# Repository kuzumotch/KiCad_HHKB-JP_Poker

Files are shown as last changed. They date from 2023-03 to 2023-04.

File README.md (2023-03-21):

# KiCad_HHKB-JP_Poker

## Summary
GH60互換疑似JISキーボードPCB  
GH60-compatible JIS-like hotswap keyboard PCB

<!--  ![Render](https://github.com/ai03-2725/JP60/blob/main/Render/Front.png)   -->

## Features  
- MITライセンスのもとでソース公開 / Open-source under the MIT license  
- Kailh製ソケットで全キーホットスワップ可能、はんだ付け無しで組み立て可能 / Fully hotswap  
- GH60対応の60％ケースで使用可能 / Compatible with GH60 standard cases  
- 一般的なキーサイズのみの日本語入力配列なので、GMKやePBTなどの標準キーキャップセットを使用可能 / Features a JIS-like key layout using standard keycap sizes   

[配列データ / Layout data](hhttp://www.keyboard-layout-editor.com/#/gists/5ac90f0792192c119a41c317cfdb1084)  
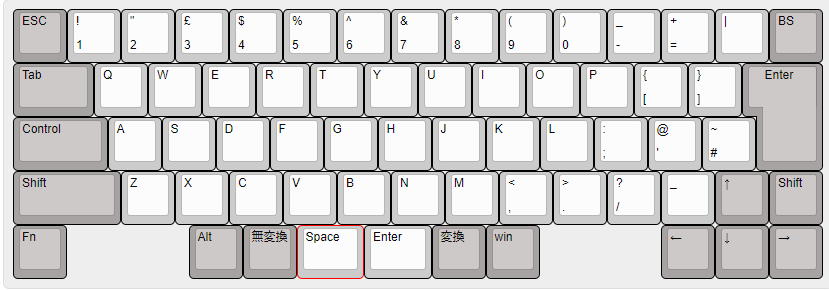
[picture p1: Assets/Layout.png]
Layout Image


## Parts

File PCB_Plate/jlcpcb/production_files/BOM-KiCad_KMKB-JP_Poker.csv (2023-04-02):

Comment | Designator | Footprint | LCSC
SMF6.0CA | D1 | D_SOD-123 | C123791
16MHz | Y1 | Crystal_SMD_3225-4Pin_3.2x2.5mm | C13738
0.1uF | C4,C5,C6 | C_0603_1608Metric | C14663
1uF | C3 | C_0603_1608Metric | C15849
22pF | C1,C2 | C_0603_1608Metric | C1653
HRO-TYPE-C-31-M-12 | USB1 | HRO-TYPE-C-31-M-12-Assembly | C165948
10uF | C7 | C_0603_1608Metric | C19702
1k | R6 | R_0603_1608Metric | C21190
5.1k | R4,R5 | R_0603_1608Metric | C23186
22 | R1,R2 | R_0603_1608Metric | C23345
10k | R3 | R_0603_1608Metric | C25804
SW_Push | SW1 | SW_SPST_TL3342 | C318884
60R@100MHz | L1 | L_1206_3216Metric | C33600
ATmega32U4-MU | U1 | QFN-44-1EP_7x7mm_P0.5mm_EP5.2x5.2mm | C45874
Polyfuse_Small | F1 | Fuse_1206_3216Metric | C70082
PRTR5V0U2X | U2 | SOT143B | C78442
SOD-123 | D10,D11,D12,D13,D14,D15,D16,D17,D18,D19,D2,D20,D21,D22,D23,D24,D25,D26,D27,D28,D29,D3,D30,D31,D32,D33,D34,D35,D36,D37,D38,D39,D4,D40,D41,D42,D43,D44,D45,D46,D47,D48,D49,D5,D50,D51,D52,D53,D54,D55,D56,D57,D58,D59,D6,D60,D61,D62,D63,D64,D65,D66,D67,D7,D8,D9 | D_SOD-123 | C81598

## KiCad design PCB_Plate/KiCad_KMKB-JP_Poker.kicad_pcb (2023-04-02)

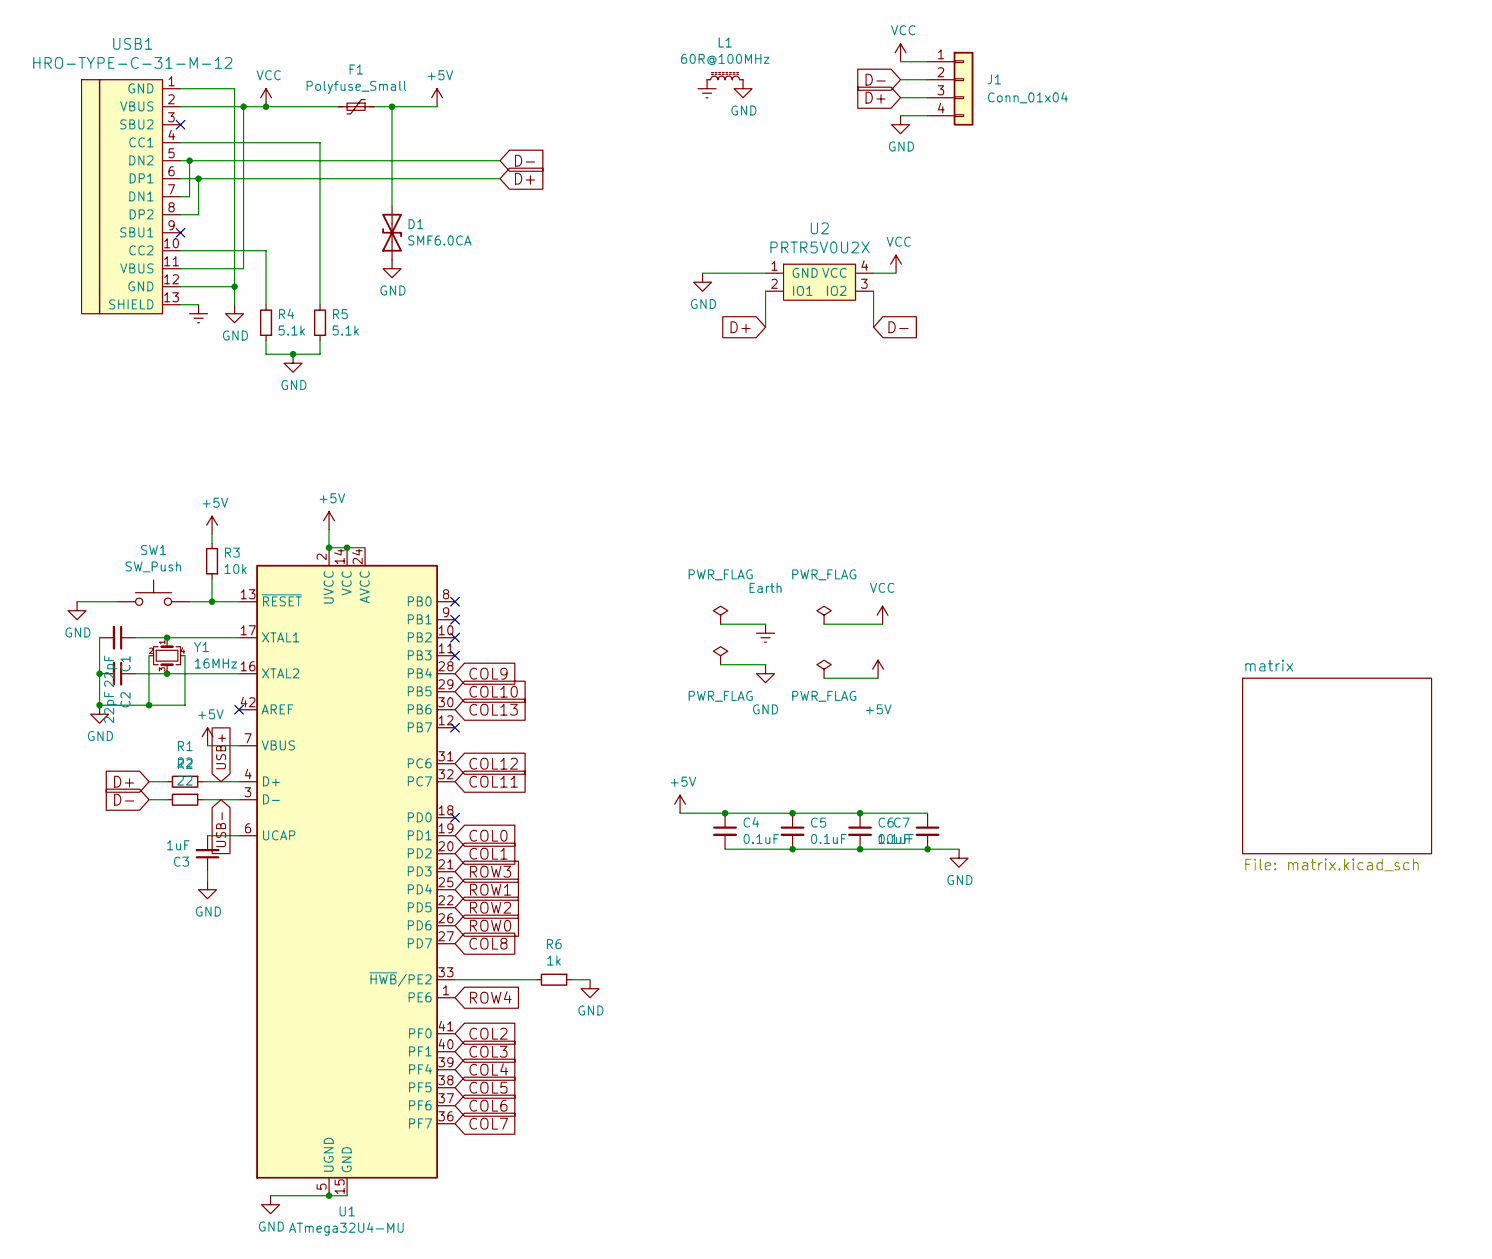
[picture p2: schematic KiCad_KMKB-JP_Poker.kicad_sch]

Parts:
C1, C2: 22pF; C_0603_1608Metric
C3: 1uF; C_0603_1608Metric
C4, C5, C6: 0.1uF; C_0603_1608Metric
C7: 10uF; C_0603_1608Metric
D1: SMF6.0CA; D_SOD-123
F1: Polyfuse_Small; Fuse_1206_3216Metric
J1: Conn_01x04; PinHeader_1x04_P2.54mm_Vertical
L1: 60R@100MHz; L_1206_3216Metric
R1, R2: 22; R_0603_1608Metric
R3: 10k; R_0603_1608Metric
R4, R5: 5.1k; R_0603_1608Metric
R6: 1k; R_0603_1608Metric
SW1: SW_Push; SW_SPST_TL3342
U1: ATmega32U4-MU; QFN-44-1EP_7x7mm_P0.5mm_EP5.2x5.2mm
U2: PRTR5V0U2X; SOT143B
USB1: HRO-TYPE-C-31-M-12; HRO-TYPE-C-31-M-12-Assembly
Y1: 16MHz; Crystal_SMD_3225-4Pin_3.2x2.5mm

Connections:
+5V: C4.1, C5.1, C6.1, C7.1, D1.2 (A2), F1.1, R3.2, U1.2 (UVCC), U1.7 (VBUS), U1.14 (VCC), U1.24 (AVCC), U1.34 (VCC), U1.44 (AVCC)
COL0: U1.19 (PD1); also elsewhere on the board
COL1: U1.20 (PD2); also elsewhere on the board
COL2: U1.41 (PF0); also elsewhere on the board
COL3: U1.40 (PF1); also elsewhere on the board
COL4: U1.39 (PF4); also elsewhere on the board
COL5: U1.38 (PF5); also elsewhere on the board
COL6: U1.37 (PF6); also elsewhere on the board
COL7: U1.36 (PF7); also elsewhere on the board
COL8: U1.27 (PD7); also elsewhere on the board
COL9: U1.28 (PB4); also elsewhere on the board
COL10: U1.29 (PB5); also elsewhere on the board
COL11: U1.32 (PC7); also elsewhere on the board
COL12: U1.31 (PC6); also elsewhere on the board
COL13: U1.30 (PB6); also elsewhere on the board
D+: J1.3, R1.2, U2.2 (IO1), USB1.6 (DP1), USB1.8 (DP2)
D-: J1.2, R2.2, U2.3 (IO2), USB1.5 (DN2), USB1.7 (DN1)
Earth: L1.1, USB1.13 (SHIELD)
GND: C1.2, C2.2, C3.1, C4.2, C5.2, C6.2, C7.2, D1.1 (A1), J1.4, L1.2, R4.1, R5.1, R6.1, SW1.1, U1.5 (UGND), U1.15 (GND), U1.23 (GND), U1.35 (GND), U1.43 (GND), U1.45 (GND), U2.1 (GND), USB1.1 (GND), USB1.12 (GND), Y1.2, Y1.4
unnamed: C1.1, U1.17 (XTAL1), Y1.1
unnamed: C2.1, U1.16 (XTAL2), Y1.3
unnamed: C3.2, U1.6 (UCAP)
unnamed: R3.1, SW1.2, U1.13 (~RESET)
unnamed: R4.2, USB1.10 (CC2)
unnamed: R5.2, USB1.4 (CC1)
unnamed: R6.2, U1.33 (~HWB/PE2)
ROW0: U1.26 (PD6); also elsewhere on the board
ROW1: U1.25 (PD4); also elsewhere on the board
ROW2: U1.22 (PD5); also elsewhere on the board
ROW3: U1.21 (PD3); also elsewhere on the board
ROW4: U1.1 (PE6); also elsewhere on the board
USB+: R1.1, U1.4 (D+)
USB-: R2.1, U1.3 (D-)
VCC: F1.2, J1.1, U2.4 (VCC), USB1.2 (VBUS), USB1.11 (VBUS)

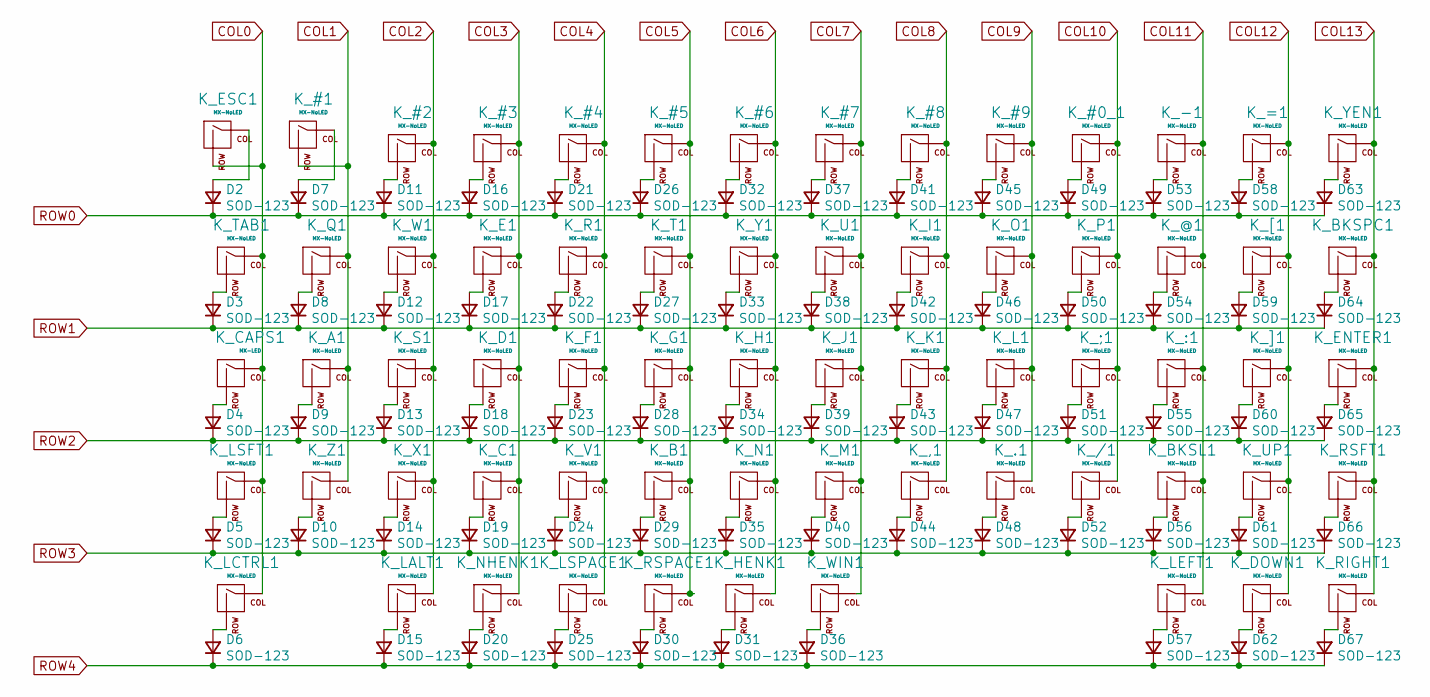
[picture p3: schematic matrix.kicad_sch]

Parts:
D2, D3, D4, D5, D6, D7, D8, D9, D10, D11, D12, D13, D14, D15, D16, D17, D18, D19, D20, D21, D22, D23, D24, D25, D26, D27, D28, D29, D30, D31, D32, D33, D34, D35, D36, D37, D38, D39, D40, D41, D42, D43, D44, D45, D46, D47, D48, D49, D50, D51, D52, D53, D54, D55, D56, D57, D58, D59, D60, D61, D62, D63, D64, D65, D66, D67: SOD-123; D_SOD-123
K_#0_1, K_#1, K_#2, K_#3, K_#4, K_#5, K_#6, K_#7, K_#8, K_#9: MX-NoLED; MXOnly-1U-Hotswap
K_,1: MX-NoLED; MXOnly-1U-Hotswap
K_-1: MX-NoLED; MXOnly-1U-Hotswap
K_.1: MX-NoLED; MXOnly-1U-Hotswap
K_/1: MX-NoLED; MXOnly-1U-Hotswap
K_:1: MX-NoLED; MXOnly-1U-Hotswap
K_;1: MX-NoLED; MXOnly-1U-Hotswap
K_=1: MX-NoLED; MXOnly-1U-Hotswap
K_@1: MX-NoLED; MXOnly-1U-Hotswap
K_A1: MX-NoLED; MXOnly-1U-Hotswap
K_B1: MX-NoLED; MXOnly-1U-Hotswap
K_BKSL1: MX-NoLED; MXOnly-1U-Hotswap
K_BKSPC1: MX-NoLED; MXOnly-1U-Hotswap
K_C1: MX-NoLED; MXOnly-1U-Hotswap
K_CAPS1: MX-LED; MXOnly-1.75U-Hotswap
K_D1: MX-NoLED; MXOnly-1U-Hotswap
K_DOWN1: MX-NoLED; MXOnly-1U-Hotswap
K_E1: MX-NoLED; MXOnly-1U-Hotswap
K_ENTER1: MX-NoLED; MXOnly-ISO-ROTATED-Hotswap
K_ESC1: MX-NoLED; MXOnly-1U-Hotswap
K_F1: MX-NoLED; MXOnly-1U-Hotswap
K_G1: MX-NoLED; MXOnly-1U-Hotswap
K_H1: MX-NoLED; MXOnly-1U-Hotswap
K_HENK1: MX-NoLED; MXOnly-1U-Hotswap
K_I1: MX-NoLED; MXOnly-1U-Hotswap
K_J1: MX-NoLED; MXOnly-1U-Hotswap
K_K1: MX-NoLED; MXOnly-1U-Hotswap
K_L1: MX-NoLED; MXOnly-1U-Hotswap
K_LALT1: MX-NoLED; MXOnly-1U-Hotswap
K_LCTRL1: MX-NoLED; MXOnly-1U-Hotswap
K_LEFT1: MX-NoLED; MXOnly-1U-Hotswap
K_LSFT1: MX-NoLED; MXOnly-2U-Hotswap
K_LSPACE1: MX-NoLED; MXOnly-1.25U-Hotswap
K_M1: MX-NoLED; MXOnly-1U-Hotswap
K_N1: MX-NoLED; MXOnly-1U-Hotswap
K_NHENK1: MX-NoLED; MXOnly-1U-Hotswap
K_O1: MX-NoLED; MXOnly-1U-Hotswap
K_P1: MX-NoLED; MXOnly-1U-Hotswap
K_Q1: MX-NoLED; MXOnly-1U-Hotswap
K_R1: MX-NoLED; MXOnly-1U-Hotswap
K_RIGHT1: MX-NoLED; MXOnly-1U-Hotswap
K_RSFT1: MX-NoLED; MXOnly-1U-Hotswap
K_RSPACE1: MX-NoLED; MXOnly-1.25U-Hotswap
K_S1: MX-NoLED; MXOnly-1U-Hotswap
K_T1: MX-NoLED; MXOnly-1U-Hotswap
K_TAB1: MX-NoLED; MXOnly-1.5U-Hotswap
K_U1: MX-NoLED; MXOnly-1U-Hotswap
K_UP1: MX-NoLED; MXOnly-1U-Hotswap
K_V1: MX-NoLED; MXOnly-1U-Hotswap
K_W1: MX-NoLED; MXOnly-1U-Hotswap
K_WIN1: MX-NoLED; MXOnly-1U-Hotswap
K_X1: MX-NoLED; MXOnly-1U-Hotswap
K_Y1: MX-NoLED; MXOnly-1U-Hotswap
K_YEN1: MX-NoLED; MXOnly-1U-Hotswap
K_Z1: MX-NoLED; MXOnly-1U-Hotswap
K_[1: MX-NoLED; MXOnly-1U-Hotswap
K_]1: MX-NoLED; MXOnly-1U-Hotswap

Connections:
COL0: K_CAPS1.1 (COL), K_ESC1.2 (ROW), K_LCTRL1.1 (COL), K_LSFT1.1 (COL), K_TAB1.1 (COL); also elsewhere on the board
COL1: K_#1.2 (ROW), K_A1.1 (COL), K_Q1.1 (COL), K_Z1.1 (COL); also elsewhere on the board
COL2: K_#2.1 (COL), K_LALT1.1 (COL), K_S1.1 (COL), K_W1.1 (COL), K_X1.1 (COL); also elsewhere on the board
COL3: K_#3.1 (COL), K_C1.1 (COL), K_D1.1 (COL), K_E1.1 (COL), K_NHENK1.1 (COL); also elsewhere on the board
COL4: K_#4.1 (COL), K_F1.1 (COL), K_LSPACE1.1 (COL), K_R1.1 (COL), K_V1.1 (COL); also elsewhere on the board
COL5: K_#5.1 (COL), K_B1.1 (COL), K_G1.1 (COL), K_RSPACE1.1 (COL), K_T1.1 (COL); also elsewhere on the board
COL6: K_#6.1 (COL), K_H1.1 (COL), K_HENK1.1 (COL), K_N1.1 (COL), K_Y1.1 (COL); also elsewhere on the board
COL7: K_#7.1 (COL), K_J1.1 (COL), K_M1.1 (COL), K_U1.1 (COL), K_WIN1.1 (COL); also elsewhere on the board
COL8: K_#8.1 (COL), K_,1.1 (COL), K_I1.1 (COL), K_K1.1 (COL); also elsewhere on the board
COL9: K_#9.1 (COL), K_.1.1 (COL), K_L1.1 (COL), K_O1.1 (COL); also elsewhere on the board
COL10: K_#0_1.1 (COL), K_/1.1 (COL), K_;1.1 (COL), K_P1.1 (COL); also elsewhere on the board
COL11: K_-1.1 (COL), K_:1.1 (COL), K_@1.1 (COL), K_BKSL1.1 (COL), K_LEFT1.1 (COL); also elsewhere on the board
COL12: K_=1.1 (COL), K_DOWN1.1 (COL), K_UP1.1 (COL), K_[1.1 (COL), K_]1.1 (COL); also elsewhere on the board
COL13: K_BKSPC1.1 (COL), K_ENTER1.1 (COL), K_RIGHT1.1 (COL), K_RSFT1.1 (COL), K_YEN1.1 (COL); also elsewhere on the board
unnamed: D2.2 (A), K_ESC1.1 (COL)
unnamed: D3.2 (A), K_TAB1.2 (ROW)
unnamed: D4.2 (A), K_CAPS1.2 (ROW)
unnamed: D5.2 (A), K_LSFT1.2 (ROW)
unnamed: D6.2 (A), K_LCTRL1.2 (ROW)
unnamed: D7.2 (A), K_#1.1 (COL)
unnamed: D8.2 (A), K_Q1.2 (ROW)
unnamed: D9.2 (A), K_A1.2 (ROW)
unnamed: D10.2 (A), K_Z1.2 (ROW)
unnamed: D11.2 (A), K_#2.2 (ROW)
unnamed: D12.2 (A), K_W1.2 (ROW)
unnamed: D13.2 (A), K_S1.2 (ROW)
unnamed: D14.2 (A), K_X1.2 (ROW)
unnamed: D15.2 (A), K_LALT1.2 (ROW)
unnamed: D16.2 (A), K_#3.2 (ROW)
unnamed: D17.2 (A), K_E1.2 (ROW)
unnamed: D18.2 (A), K_D1.2 (ROW)
unnamed: D19.2 (A), K_C1.2 (ROW)
unnamed: D20.2 (A), K_NHENK1.2 (ROW)
unnamed: D21.2 (A), K_#4.2 (ROW)
unnamed: D22.2 (A), K_R1.2 (ROW)
unnamed: D23.2 (A), K_F1.2 (ROW)
unnamed: D24.2 (A), K_V1.2 (ROW)
unnamed: D25.2 (A), K_LSPACE1.2 (ROW)
unnamed: D26.2 (A), K_#5.2 (ROW)
unnamed: D27.2 (A), K_T1.2 (ROW)
unnamed: D28.2 (A), K_G1.2 (ROW)
unnamed: D29.2 (A), K_B1.2 (ROW)
unnamed: D30.2 (A), K_RSPACE1.2 (ROW)
unnamed: D31.2 (A), K_HENK1.2 (ROW)
unnamed: D32.2 (A), K_#6.2 (ROW)
unnamed: D33.2 (A), K_Y1.2 (ROW)
unnamed: D34.2 (A), K_H1.2 (ROW)
unnamed: D35.2 (A), K_N1.2 (ROW)
unnamed: D36.2 (A), K_WIN1.2 (ROW)
unnamed: D37.2 (A), K_#7.2 (ROW)
unnamed: D38.2 (A), K_U1.2 (ROW)
unnamed: D39.2 (A), K_J1.2 (ROW)
unnamed: D40.2 (A), K_M1.2 (ROW)
unnamed: D41.2 (A), K_#8.2 (ROW)
unnamed: D42.2 (A), K_I1.2 (ROW)
unnamed: D43.2 (A), K_K1.2 (ROW)
unnamed: D44.2 (A), K_,1.2 (ROW)
unnamed: D45.2 (A), K_#9.2 (ROW)
unnamed: D46.2 (A), K_O1.2 (ROW)
unnamed: D47.2 (A), K_L1.2 (ROW)
unnamed: D48.2 (A), K_.1.2 (ROW)
unnamed: D49.2 (A), K_#0_1.2 (ROW)
unnamed: D50.2 (A), K_P1.2 (ROW)
unnamed: D51.2 (A), K_;1.2 (ROW)
unnamed: D52.2 (A), K_/1.2 (ROW)
unnamed: D53.2 (A), K_-1.2 (ROW)
unnamed: D54.2 (A), K_@1.2 (ROW)
unnamed: D55.2 (A), K_:1.2 (ROW)
unnamed: D56.2 (A), K_BKSL1.2 (ROW)
unnamed: D57.2 (A), K_LEFT1.2 (ROW)
unnamed: D58.2 (A), K_=1.2 (ROW)
unnamed: D59.2 (A), K_[1.2 (ROW)
unnamed: D60.2 (A), K_]1.2 (ROW)
unnamed: D61.2 (A), K_UP1.2 (ROW)
unnamed: D62.2 (A), K_DOWN1.2 (ROW)
unnamed: D63.2 (A), K_YEN1.2 (ROW)
unnamed: D64.2 (A), K_BKSPC1.2 (ROW)
unnamed: D65.2 (A), K_ENTER1.2 (ROW)
unnamed: D66.2 (A), K_RSFT1.2 (ROW)
unnamed: D67.2 (A), K_RIGHT1.2 (ROW)
ROW0: D2.1 (K), D7.1 (K), D11.1 (K), D16.1 (K), D21.1 (K), D26.1 (K), D32.1 (K), D37.1 (K), D41.1 (K), D45.1 (K), D49.1 (K), D53.1 (K), D58.1 (K), D63.1 (K); also elsewhere on the board
ROW1: D3.1 (K), D8.1 (K), D12.1 (K), D17.1 (K), D22.1 (K), D27.1 (K), D33.1 (K), D38.1 (K), D42.1 (K), D46.1 (K), D50.1 (K), D54.1 (K), D59.1 (K), D64.1 (K); also elsewhere on the board
ROW2: D4.1 (K), D9.1 (K), D13.1 (K), D18.1 (K), D23.1 (K), D28.1 (K), D34.1 (K), D39.1 (K), D43.1 (K), D47.1 (K), D51.1 (K), D55.1 (K), D60.1 (K), D65.1 (K); also elsewhere on the board
ROW3: D5.1 (K), D10.1 (K), D14.1 (K), D19.1 (K), D24.1 (K), D29.1 (K), D35.1 (K), D40.1 (K), D44.1 (K), D48.1 (K), D52.1 (K), D56.1 (K), D61.1 (K), D66.1 (K); also elsewhere on the board
ROW4: D6.1 (K), D15.1 (K), D20.1 (K), D25.1 (K), D30.1 (K), D31.1 (K), D36.1 (K), D57.1 (K), D62.1 (K), D67.1 (K); also elsewhere on the board

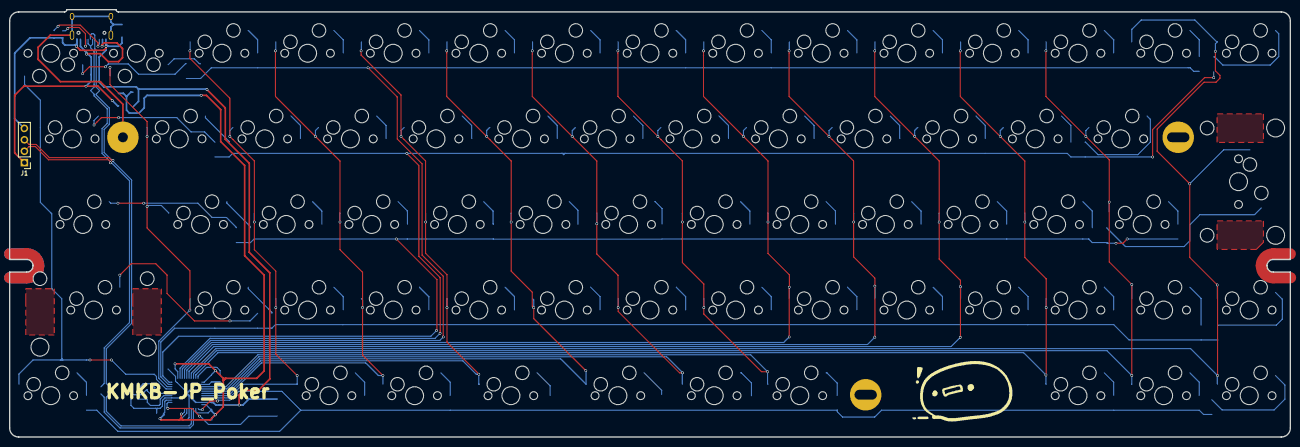
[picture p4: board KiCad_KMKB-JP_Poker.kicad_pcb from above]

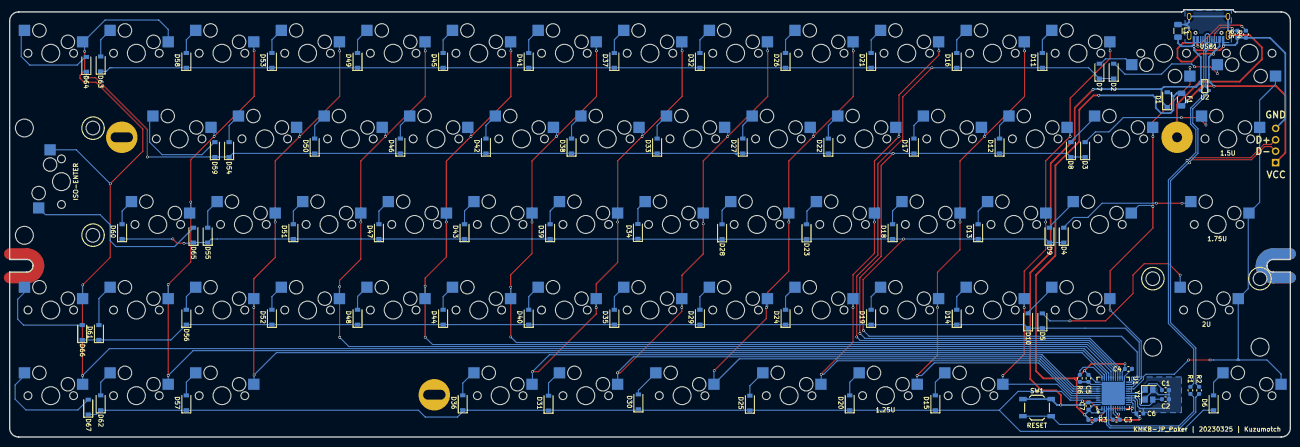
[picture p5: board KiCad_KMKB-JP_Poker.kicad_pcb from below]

Board: 2 copper layers, 285.0 x 95.1 mm, 154 parts (87 on the bottom side), 100 nets.

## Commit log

2023-03-21 initialize for KiCad_HHKB-JP_Poker
    [JP60-B_Cu.gbl, JP60-B_Mask.gbs, JP60-B_Paste.gbp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]
2023-03-21 edit symbol it does not exist in 6.0
    [KiCad_HHKB-JP_Poker.kicad_sch, matrix.kicad_sch]
2023-03-21 Edit Key Matrix
    [KiCad_HHKB-JP_Poker.kicad_sch, matrix.kicad_sch]
2023-03-21 edit footprint of Keyswitches.
    [KiCad_HHKB-JP_Poker.kicad_sch, matrix.kicad_sch]
2023-03-21 Edit sch, execute ERC, and fix warnings
    [KiCad_HHKB-JP_Poker.kicad_sch]
2023-03-21 Modify Symbol Name
    [KiCad_HHKB-JP_Poker.kicad_sch, matrix.kicad_sch]
2023-03-21 回路図に反映
2023-03-21 Create New Locallib (DZ60 Outline, but does not have center hole)
2023-03-21 Save Point 1 (Start PCB Editing)
2023-03-21 Save Point 2 (Remove ai03's logos)
    [KiCad_HHKB-JP_Poker.kicad_pcb]
2023-03-21 Save Point 3 (Remove F:Cu on R4)
    [KiCad_HHKB-JP_Poker.kicad_pcb]
2023-03-21 Save Point4 (Move MCU)
    [KiCad_HHKB-JP_Poker.kicad_pcb]
2023-03-21 Save Point 5 (Remove B:Cu on R4)
    [KiCad_HHKB-JP_Poker.kicad_pcb]
2023-03-21 Correct Symbol Names (bkspとかの辺)
    [KiCad_HHKB-JP_Poker.kicad_pcb]
2023-03-21 B.Cuの消し残しを削除
    [KiCad_HHKB-JP_Poker.kicad_pcb]
2023-03-21 RIGHT の Footprint を 1.25 -> 1U に変更
    [KiCad_HHKB-JP_Poker.kicad_pcb]
2023-03-21 KeySwitchを置き換えていく
2023-03-21 R4(zxc列)のキースイッチ配置完了
    [KiCad_HHKB-JP_Poker.kicad_pcb]
2023-03-21 R4(space列)の配置完了
    [KiCad_HHKB-JP_Poker.kicad_pcb]
2023-03-21 Diodeの配置完了
    [KiCad_HHKB-JP_Poker.kicad_pcb, KiCad_HHKB-JP_Poker.kicad_sch, matrix.kicad_sch]
2023-03-21 MCUの配置完了
    [KiCad_HHKB-JP_Poker.kicad_pcb]
2023-03-21 SAVE POINT (ここから配線タイム)
2023-03-22 配線途中1
    [KiCad_HHKB-JP_Poker.kicad_pcb]
2023-03-24 colの配線完了
    [KiCad_HHKB-JP_Poker.kicad_pcb]
2023-03-24 時間的にいったんここまで
    [KiCad_HHKB-JP_Poker.kicad_pcb, matrix.kicad_sch]
2023-03-25 回路図エディターで COL14を追加
    [KiCad_HHKB-JP_Poker.kicad_sch, matrix.kicad_sch]
2023-03-25 回路図エディターで COL14削除、結局 JP60から、 ]と backspace の位置だけ変更した
    [KiCad_HHKB-JP_Poker.kicad_sch, matrix.kicad_sch]
2023-03-25 縦（Col）の配線完了
    [KiCad_HHKB-JP_Poker.kicad_pcb, KiCad_HHKB-JP_Poker.kicad_sch, matrix.kicad_sch]
2023-03-25 key switch 間の配線は完了。これから、Key Switch と MCUを使う
    [KiCad_HHKB-JP_Poker.kicad_pcb]
2023-03-25 配線完了（検算はこれから）
    [KiCad_HHKB-JP_Poker.kicad_pcb, KiCad_HHKB-JP_Poker.kicad_sch]
2023-03-25 検算完了！完成！
    [KiCad_HHKB-JP_Poker.kicad_pcb, KiCad_HHKB-JP_Poker.kicad_sch, matrix.kicad_sch]
2023-03-25 ねじ穴のMask削除&中央下をねじ穴に
    [KiCad_HHKB-JP_Poker.kicad_pcb]
2023-03-25 電源配線を穴を避けて配線しなおした
    [KiCad_HHKB-JP_Poker.kicad_pcb]
2023-03-25 DRCチェック（未配線を修正）
    [KiCad_HHKB-JP_Poker.kicad_pcb]
2023-03-25 微修正完了
    [KiCad_HHKB-JP_Poker.kicad_pcb]
2023-03-25 HHKB -> HMKB へ変更。 / ロゴの位置を変更
    [KiCad_HHKB-JP_Poker.kicad_pcb]
2023-03-25 ファイル名変更 HHKB -> KMKB & フォルダ構成変更
    [JLCSMT_Sample_BOM1.xlsx, KiCad_KMKB-JP_Poker.kicad_pcb, KiCad_KMKB-JP_Poker.kicad_sch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]
2023-03-25 フォルダ構造を大胆に変更（バグったとしたらココ）
    [JLCSMT_Sample_BOM1.xlsx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]
2023-03-29 ドーターボード用の配線穴を設置
    [KiCad_KMKB-JP_Poker.kicad_pcb, KiCad_KMKB-JP_Poker.kicad_sch]
2023-03-29 ドーターボード用の配線穴の位置を微修正
    [KiCad_KMKB-JP_Poker.kicad_pcb]
2023-03-31 シルクを修正
    [KiCad_KMKB-JP_Poker.kicad_pcb]
2023-03-31 JCLPCBに発注しました
    [BOM-KiCad_KMKB-JP_Poker.csv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]
2023-04-02 remove ゴミファイル
    [JLCSMT_Sample_BOM1.xlsx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]
2023-04-02 SWソケットを BOMとPOSファイルから削除
    [BOM-KiCad_KMKB-JP_Poker.csv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]
